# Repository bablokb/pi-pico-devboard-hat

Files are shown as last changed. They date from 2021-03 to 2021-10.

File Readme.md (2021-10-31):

Pi-Pico-Devboard-Hat
====================

This repository contains the KiCAD project files of a Pico development hat.

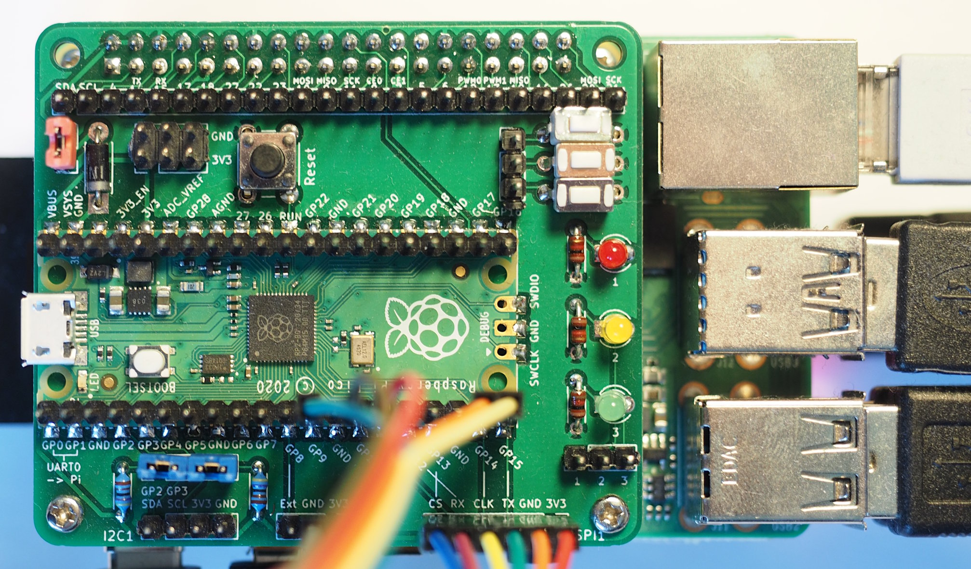
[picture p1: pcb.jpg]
Pi-Pico-Devboard-Hat


The hat connects power, UART0 and the debug-port of the pico to the
respective pins of the Pi. You will also find a number of buttons, LEDs,
an I2C-connector with pullups (controlled by jumpers), and an SPI-connector.

The design uses only through-hole components, so soldering should be easy.
The Pico is soldered directly to the hat, thanks to the castellated holes
this is no major problem. Just watch out that you don't accidently fill
the holes if you also want to attach headers directly to the Pico (which
you most certainly want to do).

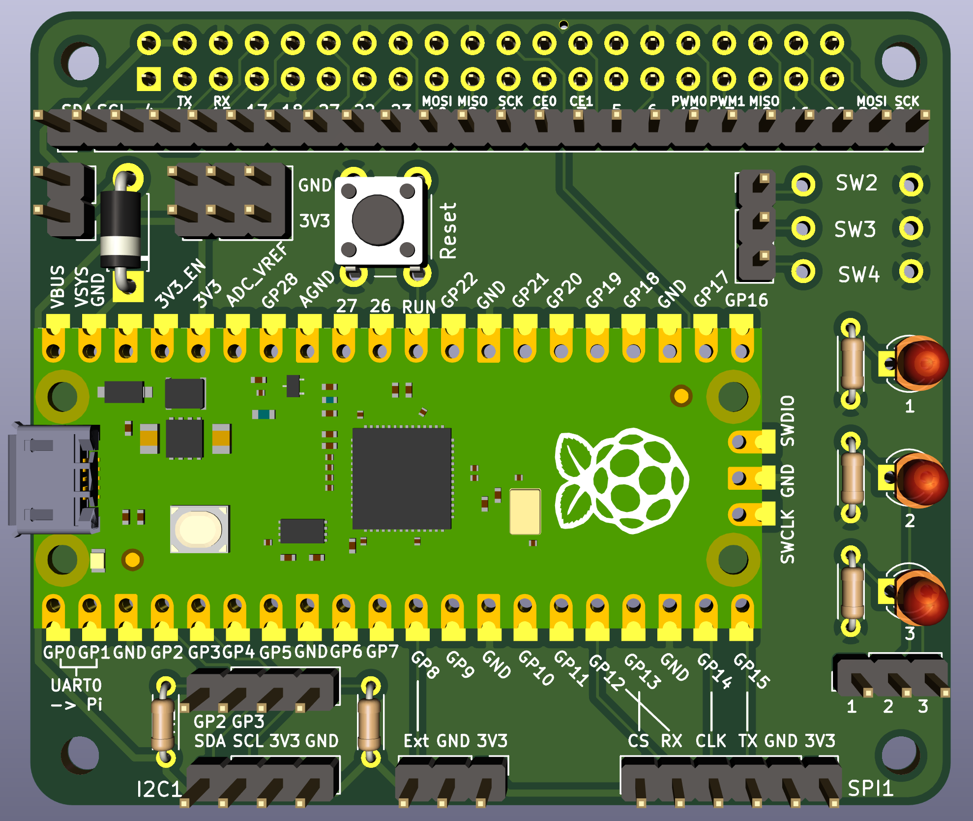
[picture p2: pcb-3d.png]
3D-view


Schematic
---------

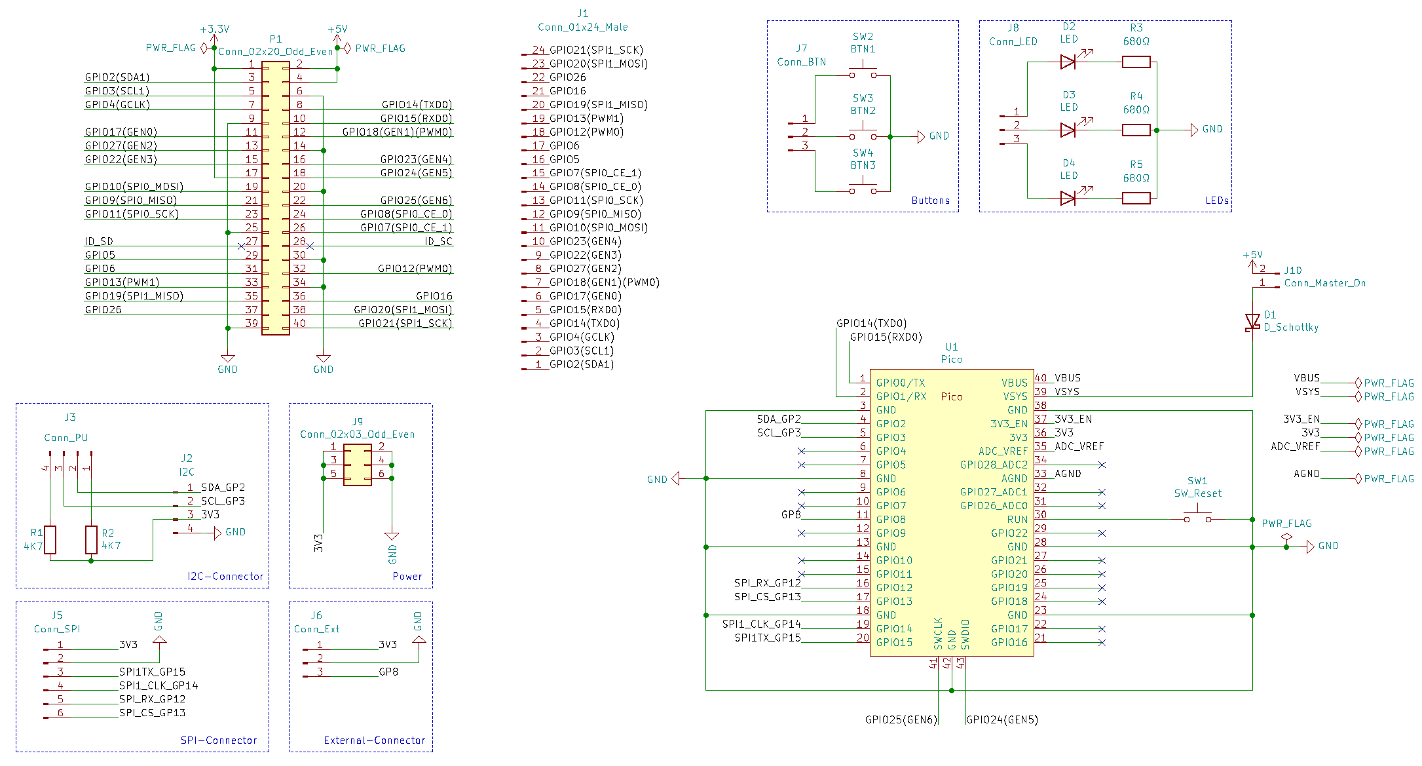
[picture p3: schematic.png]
schematic


Layout
------

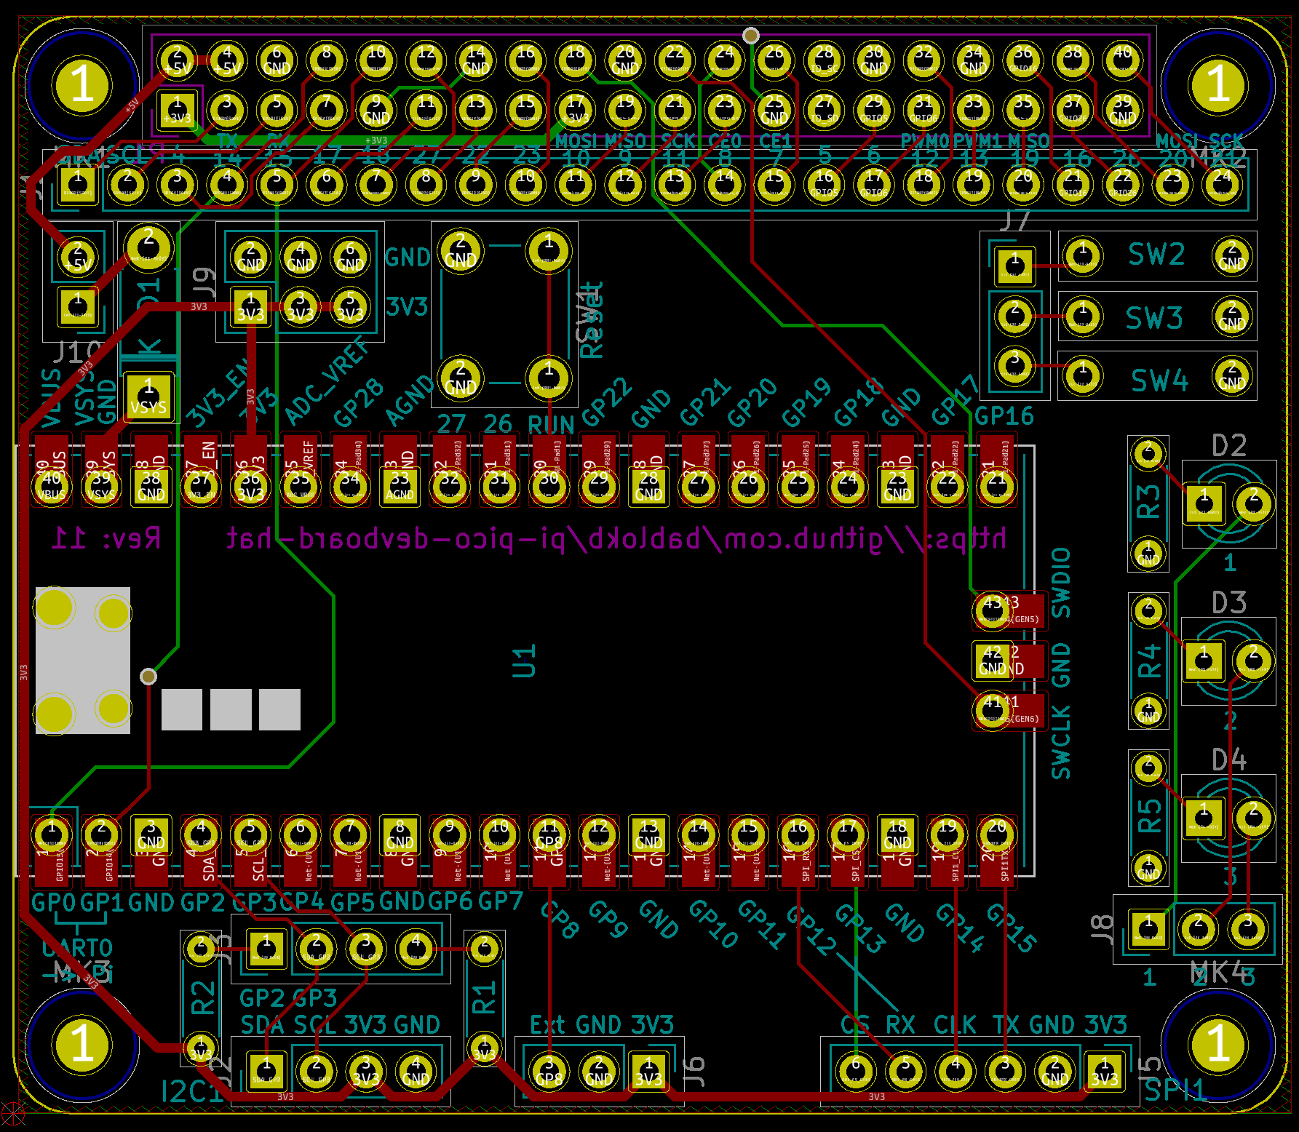
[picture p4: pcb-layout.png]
Layout


License
-------

Shield: [![CC BY-SA 4.0][cc-by-sa-shield]][cc-by-sa]

This work is licensed under a
[Creative Commons Attribution-ShareAlike 4.0 International
License][cc-by-sa].

[][cc-by-sa]

[cc-by-sa]: http://creativecommons.org/licenses/by-sa/4.0/
[cc-by-sa-image]: https://licensebuttons.net/l/by-sa/4.0/88x31.png
[cc-by-sa-shield]:
https://img.shields.io/badge/License-CC%20BY--SA%204.0-lightgrey.svg

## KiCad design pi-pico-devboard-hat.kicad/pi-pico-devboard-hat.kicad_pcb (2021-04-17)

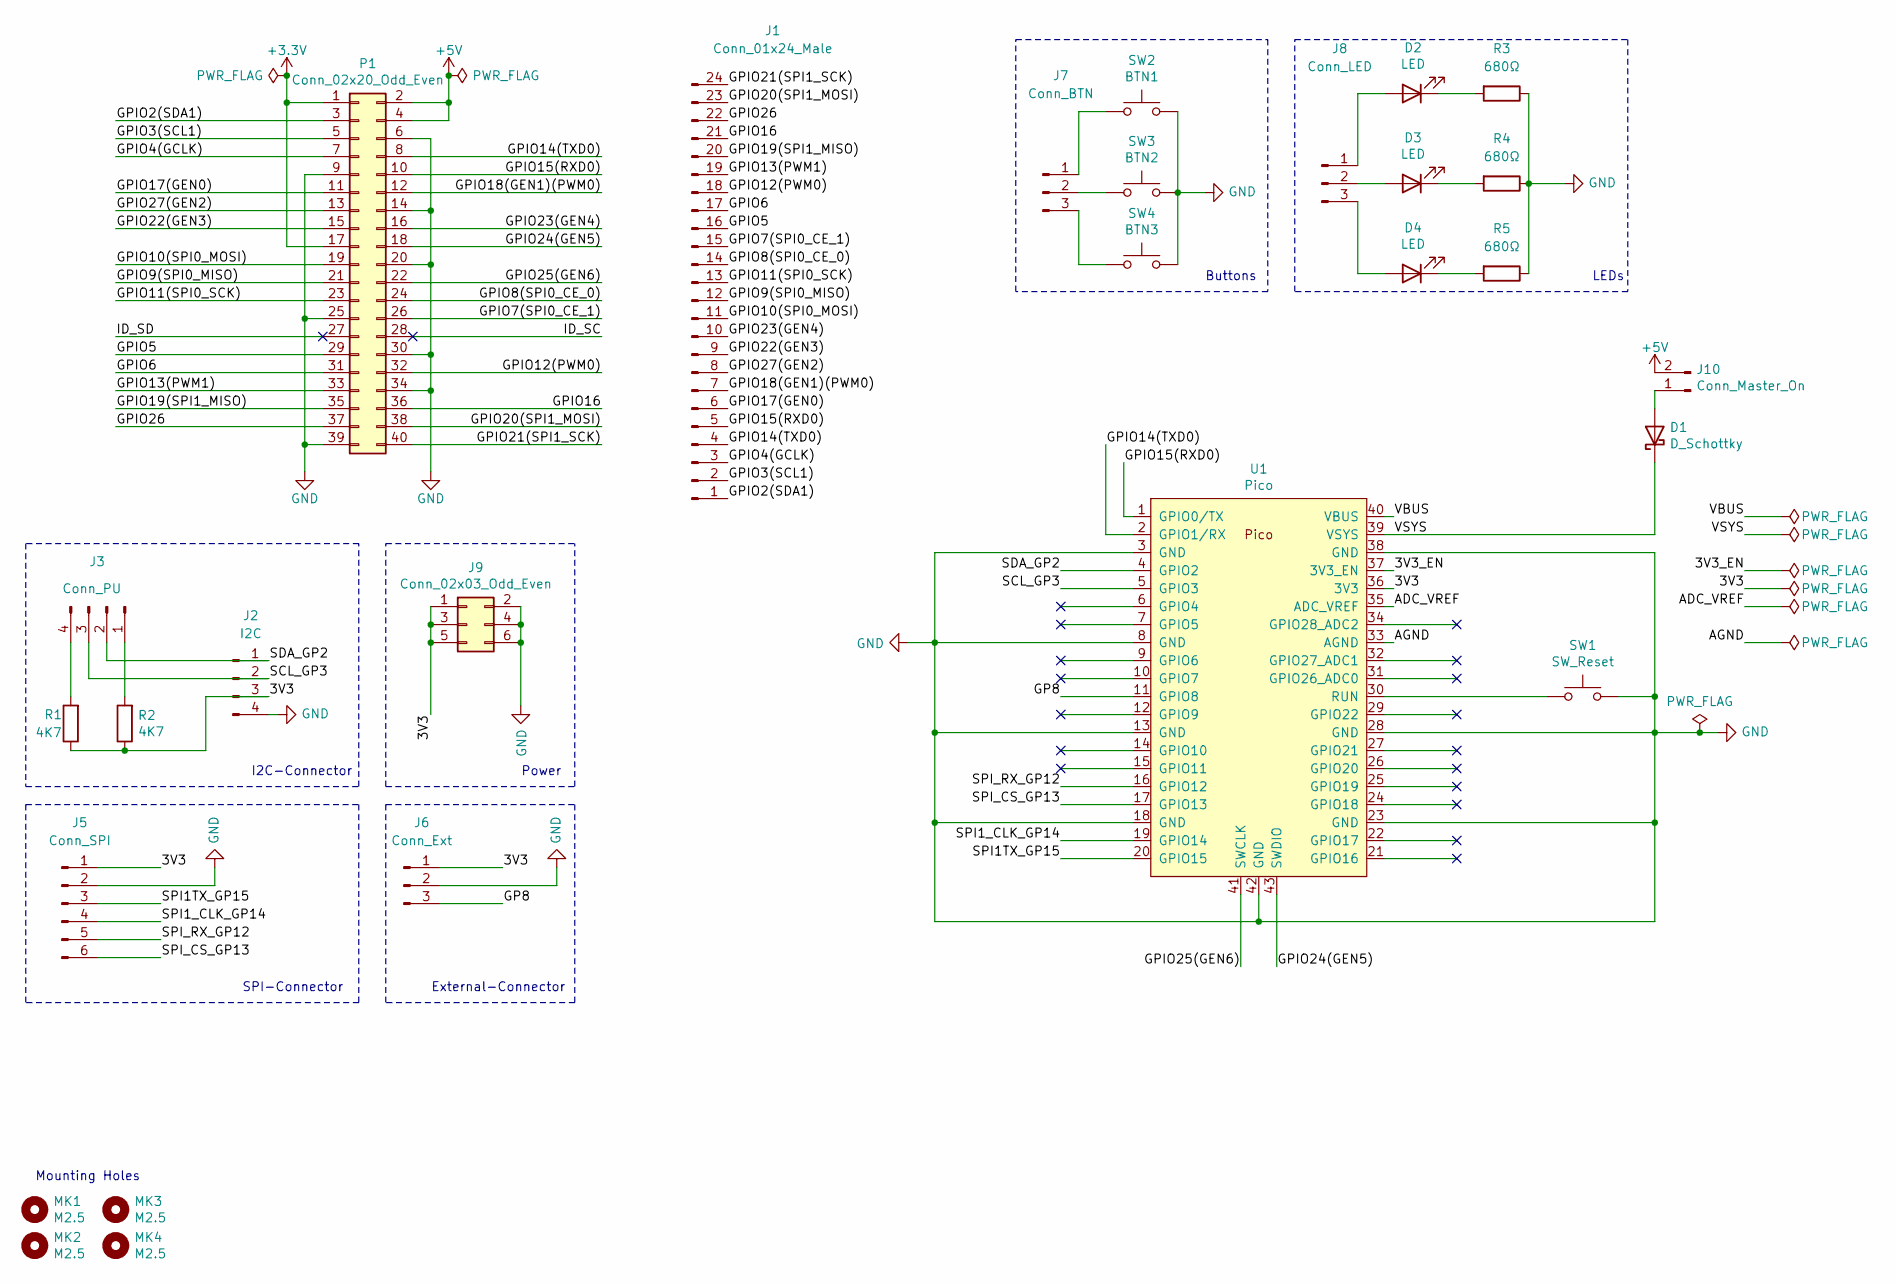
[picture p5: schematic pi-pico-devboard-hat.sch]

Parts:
D1: D_Schottky; D_DO-41_SOD81_P7.62mm_Horizontal
D2, D3, D4: LED; LED_D3.0mm
J1: Conn_01x24_Male; PinHeader_1x24_P2.54mm_Vertical
J2: I2C; PinHeader_1x04_P2.54mm_Vertical
J3: Conn_PU; PinHeader_1x04_P2.54mm_Vertical
J5: Conn_SPI; PinHeader_1x06_P2.54mm_Vertical
J6: Conn_Ext; PinHeader_1x03_P2.54mm_Vertical
J7: Conn_BTN; PinHeader_1x03_P2.54mm_Vertical
J8: Conn_LED; PinHeader_1x03_P2.54mm_Vertical
J9: Conn_02x03_Odd_Even; PinHeader_2x03_P2.54mm_Vertical
J10: Conn_Master_On; PinHeader_1x02_P2.54mm_Vertical
MK1, MK2, MK3, MK4: M2.5; MountingHole_2.7mm_M2.5
P1: Conn_02x20_Odd_Even; PinSocket_2x20_P2.54mm_Vertical
R1, R2: 4K7; R_Axial_DIN0204_L3.6mm_D1.6mm_P5.08mm_Horizontal
R3, R4, R5: 680Ω; R_Axial_DIN0204_L3.6mm_D1.6mm_P5.08mm_Horizontal
SW1: SW_Reset; SW_PUSH_6mm
SW2: BTN1; SW_PUSH_SLIM_1x4
SW3: BTN2; SW_PUSH_SLIM_1x4
SW4: BTN3; SW_PUSH_SLIM_1x4
U1: Pico; RPi_Pico_SMD_TH

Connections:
+3V3: P1.1, P1.17
+5V: J10.2, P1.2, P1.4
/3V3: J2.3, J5.1, J6.1, J9.1, J9.3, J9.5, R1.1, R2.1, U1.36 (3V3)
/3V3_EN: U1.37 (3V3_EN)
/ADC_VREF: U1.35 (ADC_VREF)
/AGND: U1.33 (AGND)
/GP8: J6.3, U1.11 (GPIO8)
/GPIO2(SDA1): J1.1, P1.3
/GPIO3(SCL1): J1.2, P1.5
/GPIO4(GCLK): J1.3, P1.7
/GPIO5: J1.16, P1.29
/GPIO6: J1.17, P1.31
/GPIO7(SPI0_CE_1): J1.15, P1.26
/GPIO8(SPI0_CE_0): J1.14, P1.24
/GPIO9(SPI0_MISO): J1.12, P1.21
/GPIO10(SPI0_MOSI): J1.11, P1.19
/GPIO11(SPI0_SCK): J1.13, P1.23
/GPIO12(PWM0): J1.18, P1.32
/GPIO13(PWM1): J1.19, P1.33
/GPIO14(TXD0): J1.4, P1.8, U1.2 (GPIO1/RX)
/GPIO15(RXD0): J1.5, P1.10, U1.1 (GPIO0/TX)
/GPIO16: J1.21, P1.36
/GPIO17(GEN0): J1.6, P1.11
/GPIO18(GEN1)(PWM0): J1.7, P1.12
/GPIO19(SPI1_MISO): J1.20, P1.35
/GPIO20(SPI1_MOSI): J1.23, P1.38
/GPIO21(SPI1_SCK): J1.24, P1.40
/GPIO22(GEN3): J1.9, P1.15
/GPIO23(GEN4): J1.10, P1.16
/GPIO24(GEN5): P1.18, U1.43 (SWDIO)
/GPIO25(GEN6): P1.22, U1.41 (SWCLK)
/GPIO26: J1.22, P1.37
/GPIO27(GEN2): J1.8, P1.13
/ID_SC: P1.28
/ID_SD: P1.27
/SCL_GP3: J2.2, J3.3, U1.5 (GPIO3)
/SDA_GP2: J2.1, J3.2, U1.4 (GPIO2)
/SPI1TX_GP15: J5.3, U1.20 (GPIO15)
/SPI1_CLK_GP14: J5.4, U1.19 (GPIO14)
/SPI_CS_GP13: J5.6, U1.17 (GPIO13)
/SPI_RX_GP12: J5.5, U1.16 (GPIO12)
/VBUS: U1.40 (VBUS)
/VSYS: D1.1 (K), U1.39 (VSYS)
GND: J2.4, J5.2, J6.2, J9.2, J9.4, J9.6, P1.6, P1.9, P1.14, P1.20, P1.25, P1.30, P1.34, P1.39, R3.1, R4.1, R5.1, SW1.2, SW2.2, SW3.2, SW4.2, U1.3 (GND), U1.8 (GND), U1.13 (GND), U1.18 (GND), U1.23 (GND), U1.28 (GND), U1.38 (GND), U1.42 (GND)
unnamed: D1.2 (A), J10.1
unnamed: D2.1 (K), R3.2
unnamed: D2.2 (A), J8.1
unnamed: D3.1 (K), R4.2
unnamed: D3.2 (A), J8.2
unnamed: D4.1 (K), R5.2
unnamed: D4.2 (A), J8.3
unnamed: J3.1, R2.2
unnamed: J3.4, R1.2
unnamed: J7.1, SW2.1
unnamed: J7.2, SW3.1
unnamed: J7.3, SW4.1
unnamed: SW1.1, U1.30 (RUN)

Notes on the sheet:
Mounting Holes
I2C-Connector
SPI-Connector
External-Connector
Buttons
LEDs
Power

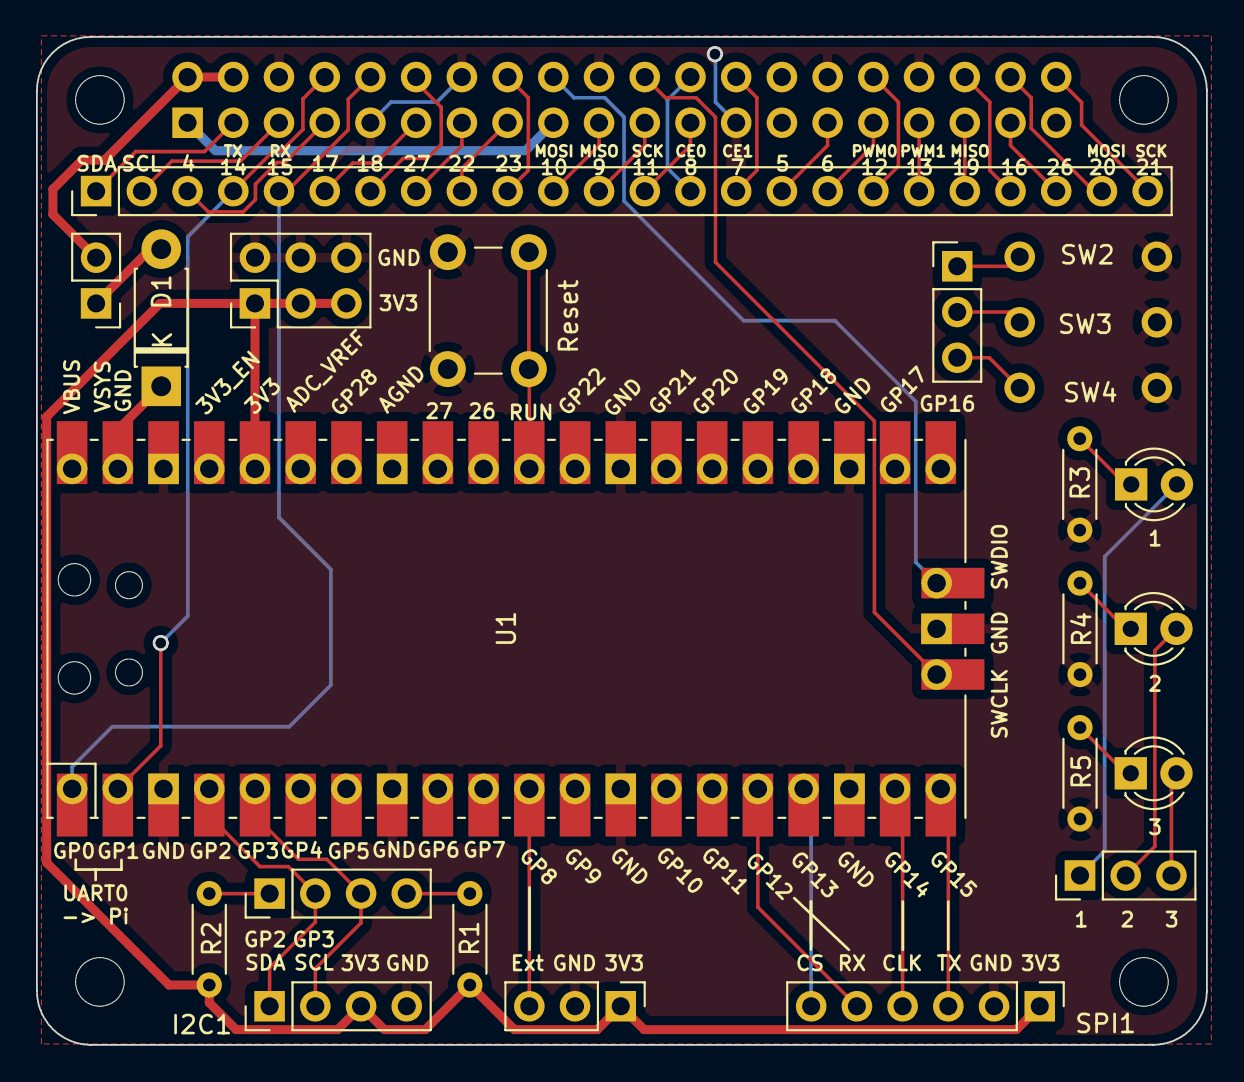
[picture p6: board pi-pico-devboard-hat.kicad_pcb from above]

Board: 2 copper layers, 65.0 x 56.0 mm, 28 parts (1 on the bottom side), 51 nets.

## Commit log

2021-03-16 added footprints
    [pi-pico-devboard-hat.sch]
2021-03-16 updated footprint for pico
    [pi-pico-devboard-hat.sch]
2021-03-18 first prototype DRC error free
    [pi-pico-devboard-hat.kicad_pcb]
2021-03-18 Rev 2: removed unneeded connectors
    [pi-pico-devboard-hat.kicad_pcb, pi-pico-devboard-hat.sch]
2021-03-20 Rev 3: added IC-connector with optional pullups
    [pi-pico-devboard-hat.kicad_pcb, pi-pico-devboard-hat.sch]
2021-03-22 Rev 4: added SPI1-connector
    [pi-pico-devboard-hat.kicad_pcb, pi-pico-devboard-hat.sch]
2021-03-23 Rev 5: added external connector
    [pi-pico-devboard-hat.kicad_pcb, pi-pico-devboard-hat.sch]
2021-03-23 Rev 6: added buttons
    [pi-pico-devboard-hat.kicad_pcb, pi-pico-devboard-hat.sch]
2021-03-23 Rev 7: added LEDs
    [pi-pico-devboard-hat.kicad_pcb, pi-pico-devboard-hat.sch]
2021-03-23 Rev 8: added power-connector / fine-tuning
    [pi-pico-devboard-hat.kicad_pcb, pi-pico-devboard-hat.sch]
2021-03-27 Rev 9: added master power-jumper
    [pi-pico-devboard-hat.kicad_pcb, pi-pico-devboard-hat.sch]
2021-03-27 Rev 9.1: changed trace for 3V3
    [pi-pico-devboard-hat.kicad_pcb]
2021-03-27 Rev 10: reorg of I2C-pullup connector
    [pi-pico-devboard-hat.kicad_pcb, pi-pico-devboard-hat.sch]
2021-03-27 Rev 11: connect Pi-pins GPIO16/GPIO26 to pin-connector (remove GPIO24/GPIO25 used for SWD)
    [pi-pico-devboard-hat.kicad_pcb, pi-pico-devboard-hat.sch]
2021-03-27 fixed labels of Pi-pin-connector
    [pi-pico-devboard-hat.kicad_pcb]
2021-04-17 fixed footprint and position of SW2-SW4
    [pi-pico-devboard-hat.kicad_pcb]
